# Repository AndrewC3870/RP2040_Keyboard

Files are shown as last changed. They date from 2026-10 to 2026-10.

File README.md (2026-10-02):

# RP2040_Keyboard
**Custom RP2040 mini keyboard for small portable projects!**
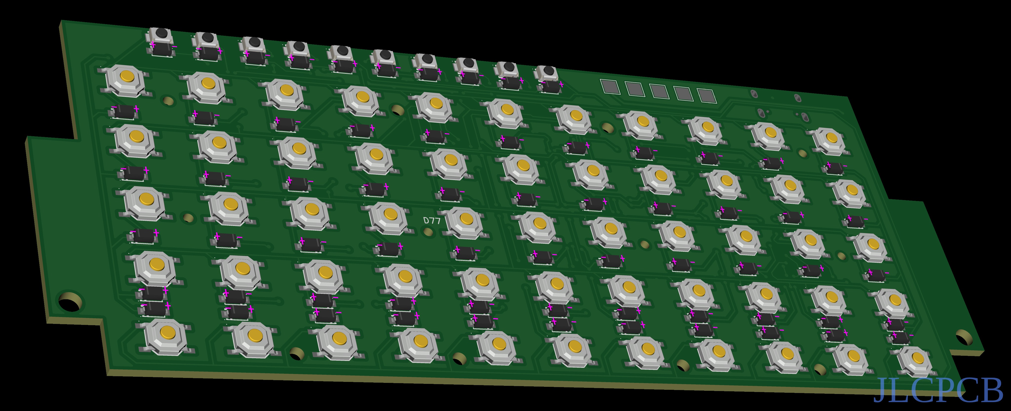
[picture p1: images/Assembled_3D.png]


## Features
* **Microcontroller:** RP2040
* **Layout:** 5x13 Ortholinear
* **Special Features:** Integrated Left D-pad and Right Action buttons directly in the QMK matrix.
* **Firmware:** QMK
---
## Keymap Layout
The default keymap includes a standard typing base layer, an Fn layer with navigation and F-keys, and dedicated hardware gamepad keys mapped to the outer columns (this was made using simple buttons footprint for custom soldering, also can be replaced with functional buttons).

* **Gamepad Left:** `Up`, `Down`, `Left`, `Right`
* **Gamepad Right:** `Y`, `A`, `X`, `B`
* **Bumpers:** `Page Up` (L1), `Page Down` (R1)

Also the test pads I added can be used to solder analog devices such as joystick or analog trigger.
If decided to add this features, then you'll need to add this changes into code and configure the keyboard.

---
## Flashing Instructions
**The code is for my specific build, but it can be easily change to satisfy your requirements**

To compile and flash this firmware, you will need the [QMK CLI](https://docs.qmk.fm/#/newbs_getting_started) installed.

1. Clone the `qmk_firmware` repository.
2. Clone or download this repository and place the `rp2040_keyboard` folder from `setup` into `qmk_firmware/keyboards/`.
3. Put your keyboard into bootloader mode.
4. Run the following command from the root of your `qmk_firmware` directory:

```bash
qmk flash -kb rp2040_keyboard -km default

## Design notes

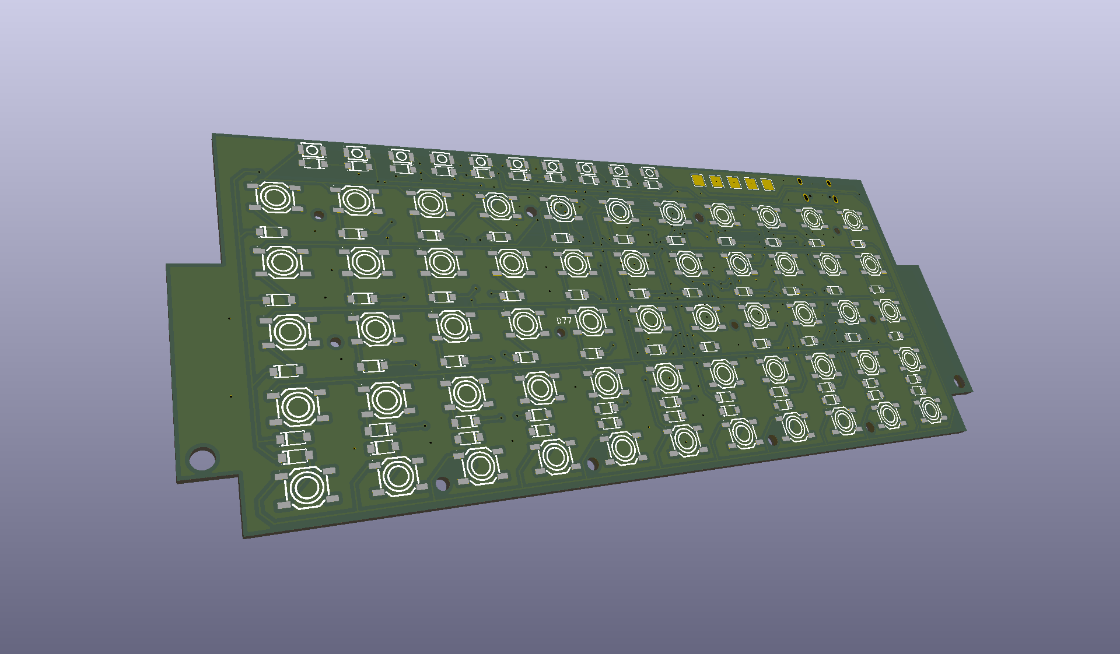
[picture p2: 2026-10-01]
images/keyboard_1.png

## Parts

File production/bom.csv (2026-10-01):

Designator | Footprint | Quantity | Value | LCSC Part #
100NF1, 100NF10, 100NF11, 100NF12, 100NF2, 100NF3, 100NF4, 100NF5, 100NF6, 100NF7, 100NF8, 100NF9 | C0603 | 12 | CC0603KRX7R8BB104 | C92490
10K1, 10K2, 10K3 | R0603 | 3 | RC0603FR-0710KL | C98220
15PF1, 15PF2 | C0603 | 2 | CC0603JRNPO9BN150 | C107037
1K1, 1K2 | R0603 | 2 | RC0603FR-071KL | C22548
1ΜF1, 1ΜF2, 1ΜF3, 1ΜF4 | C0805 | 4 | CC0805KKX5R6BB106 | C89832
27R1, 27R2 | R0603 | 2 | RC0603FR-0727RL | C137753
3V3, CLICK1, GND1, X2, Y1 | TestPoint_Pad_2.5x2.5mm | 5 | TestPoint
BOOT1, RESET1, SW1, SW10, SW11, SW12, SW13, SW14, SW15, SW16, SW17, SW18, SW19, SW2, SW20, SW21, SW22, SW23, SW24, SW25, SW26, SW27, SW28, SW29, SW3, SW30, SW31, SW32, SW33, SW34, SW35, SW36, SW37, SW38, SW39, SW4, SW40, SW41, SW42, SW43, SW44, SW45, SW46, SW47, SW48, SW49, SW5, SW50, SW51, SW52, SW53, SW54, SW55, SW6, SW7, SW8, SW9 | SW-SMD_4P-L5.2-W5.2-P3.70-LS6.4 | 57 | K2-1187SQ-A1SW-06 | C707331
D1 | SOT-23-6_L2.9-W1.6-P0.95-LS2.8-BL | 1 | USBLC6-2SC6 | C7519
D100, D111, D112, D113, D114, D115, D116, D117, D118, D119, D120, D121, D122, D123, D124, D125, D126, D127, D128, D129, D130, D131, D132, D133, D134, D135, D136, D137, D138, D139, D140, D66, D67, D68, D69, D70, D71, D72, D73, D74, D75, D76, D77, D78, D79, D80, D81, D82, D83, D84, D85, D86, D87, D88, D89, D90, D91, D92, D93, D94, D95, D96, D97, D98, D99 | SOD-123_L2.8-W1.8-LS3.7-RD | 65 | 1N4148W-C84367 | C84367
R1_5K1, R2_5K1 | R0603 | 2 | RC0603FR-075K1L | C105580
SW56, SW57, SW58, SW59, SW60, SW61, SW62, SW63, SW64, SW65 | KEY-SMD_B3U-1000PM | 10 | B3U-1000P | C231329
U1 | LQFN-56_L7.0-W7.0-P0.4-EP | 1 | RP2040 | C2040
U2 | SOT-25-5_L2.9-W1.6-P0.95-LS2.8-BL | 1 | AP2112K-3.3TRG1 | C51118
U3 | SOIC-8_L5.3-W5.3-P1.27-LS8.0-BL | 1 | W25Q16JVSSIQ | C82317
USBC1 | USB-C_SMD-TYPE-C-31-M-12_1 | 1 | TYPE-C-31-M-12 | C165948
X1 | CRYSTAL-SMD_4P-L3.2-W2.5-BL | 1 | X322512MOB4SI | C70565

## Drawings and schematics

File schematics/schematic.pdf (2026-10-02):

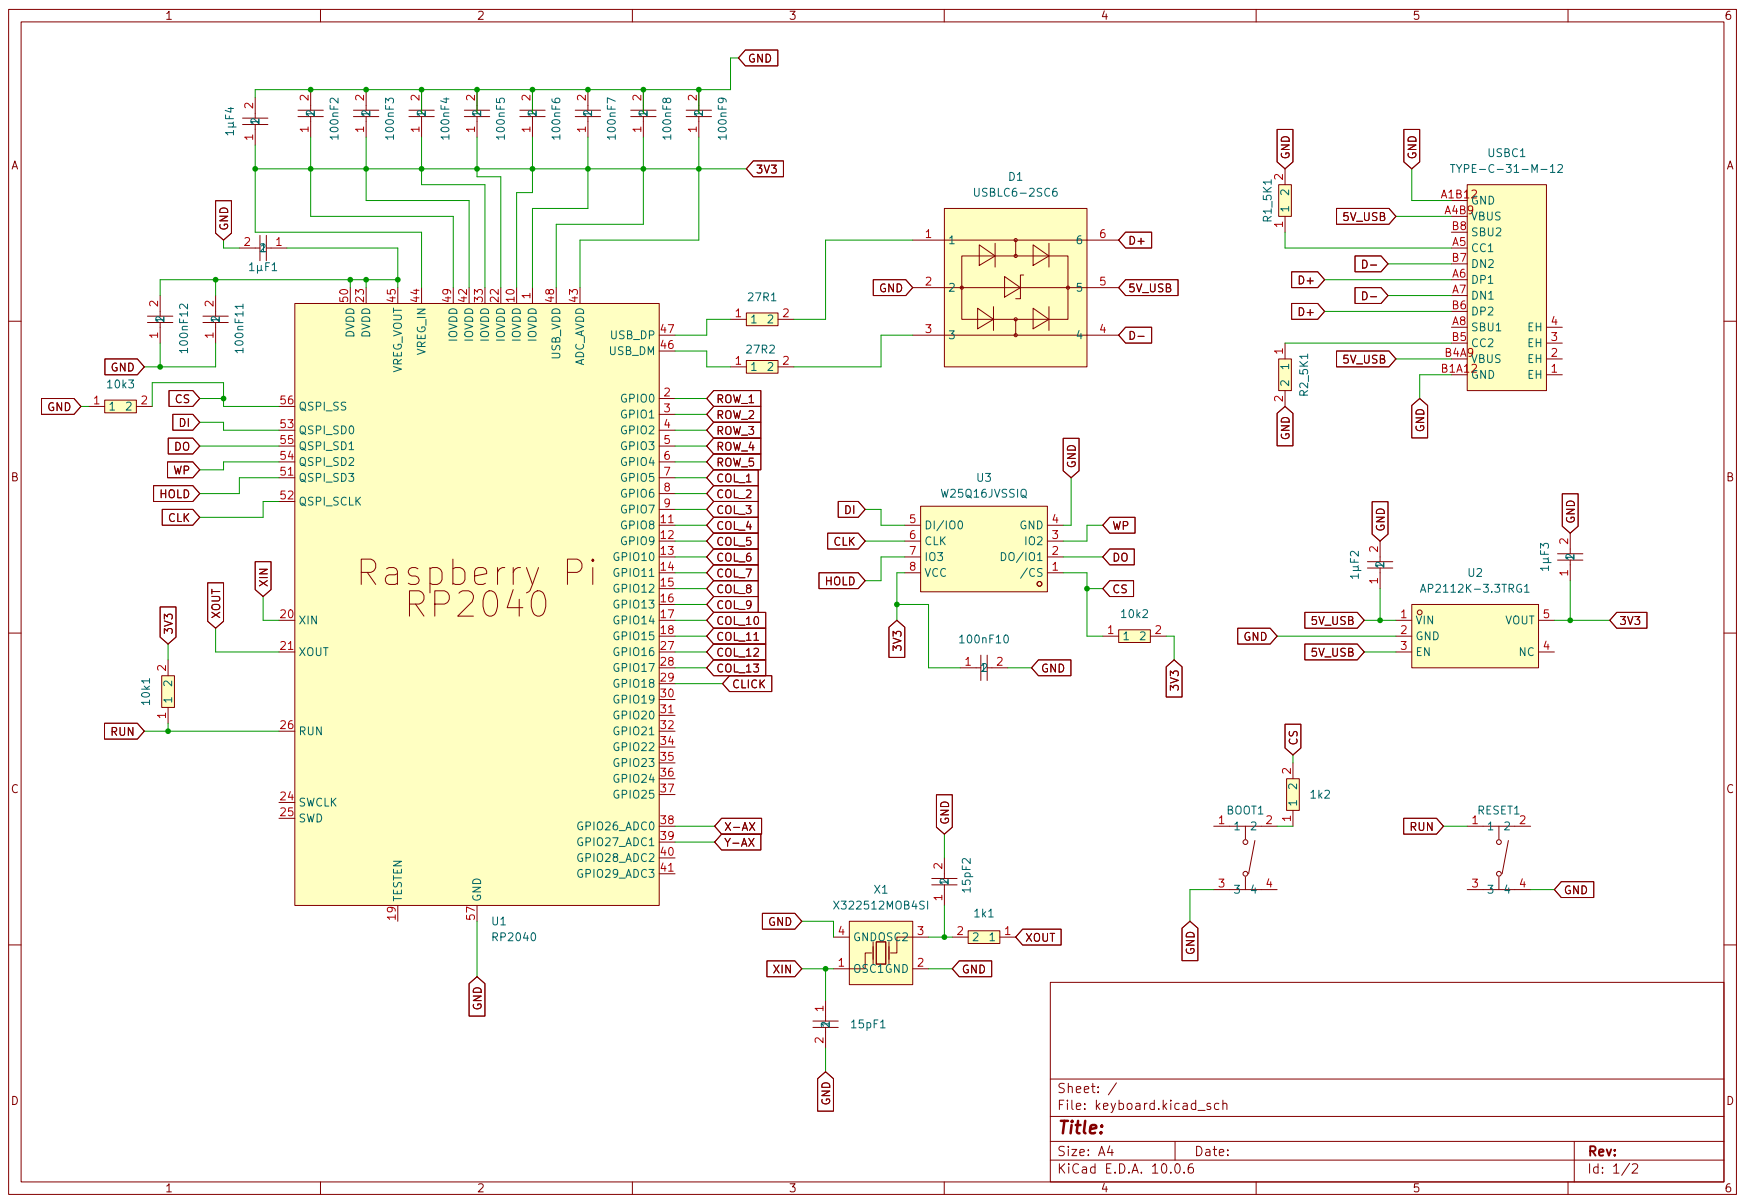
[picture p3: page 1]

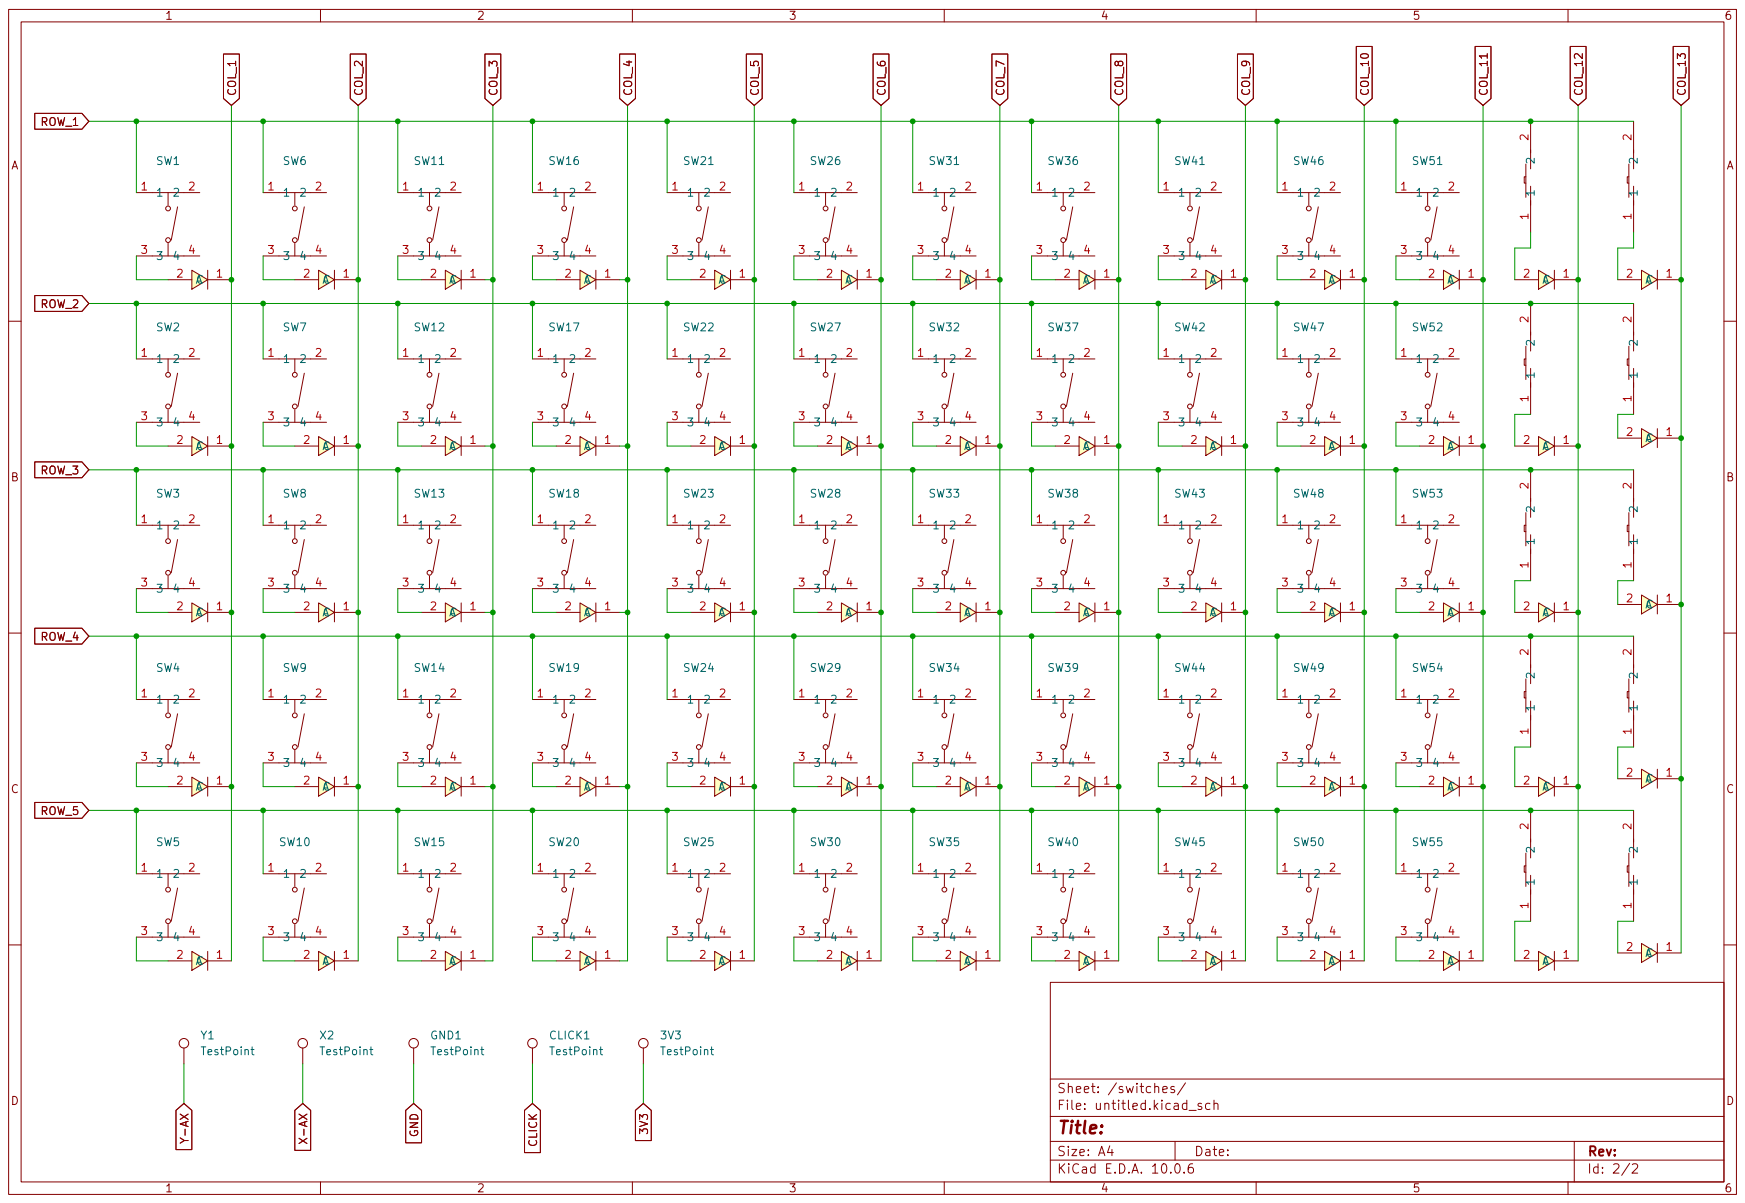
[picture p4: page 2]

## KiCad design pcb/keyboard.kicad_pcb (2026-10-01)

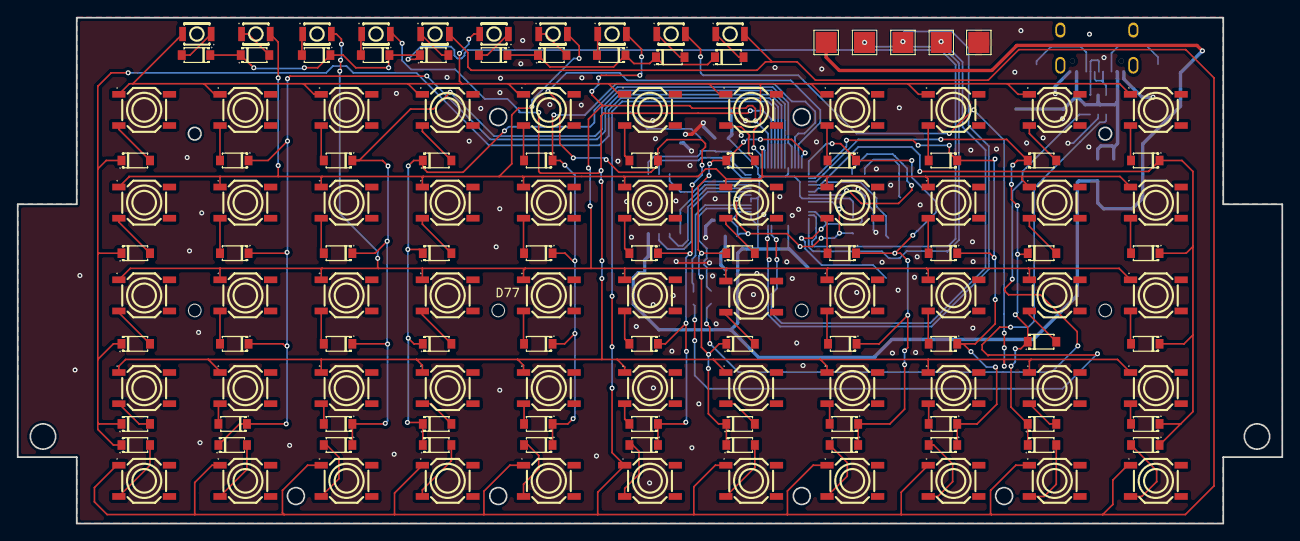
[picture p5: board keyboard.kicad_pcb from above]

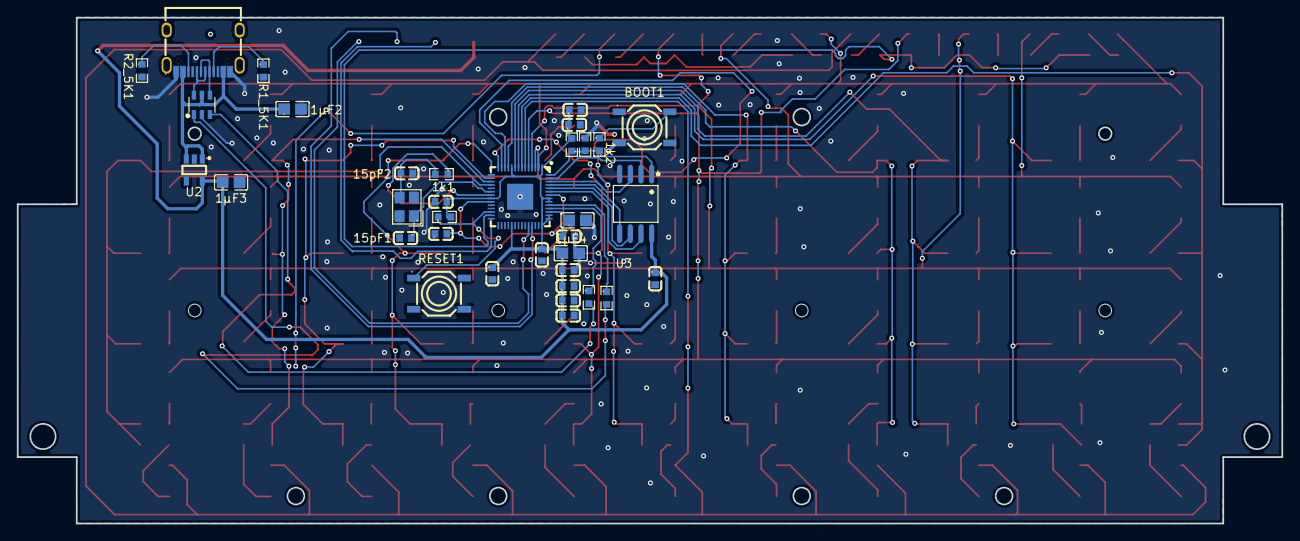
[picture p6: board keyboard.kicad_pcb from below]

Board: 2 copper layers, 150.0 x 60.0 mm, 170 parts (35 on the bottom side), 109 nets.

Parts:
1k1, 1k2: RC0603FR-071KL; R0603
1µF1, 1µF2, 1µF3, 1µF4: CC0805KKX5R6BB106; C0805
3V3: TestPoint; TestPoint_Pad_2.5x2.5mm
10k1, 10k2, 10k3: RC0603FR-0710KL; R0603
15pF1, 15pF2: CC0603JRNPO9BN150; C0603
27R1, 27R2: RC0603FR-0727RL; R0603
100nF1, 100nF2, 100nF3, 100nF4, 100nF5, 100nF6, 100nF7, 100nF8, 100nF9, 100nF10, 100nF11, 100nF12: CC0603KRX7R8BB104; C0603
BOOT1: K2-1187SQ-A1SW-06; SW-SMD_4P-L5.2-W5.2-P3.70-LS6.4
CLICK1: TestPoint; TestPoint_Pad_2.5x2.5mm
D1: USBLC6-2SC6; SOT-23-6_L2.9-W1.6-P0.95-LS2.8-BL
D66, D67, D68, D69, D70, D71, D72, D73, D74, D75, D76, D77, D78, D79, D80, D81, D82, D83, D84, D85, D86, D87, D88, D89, D90, D91, D92, D93, D94, D95, D96, D97, D98, D99, D100, D111, D112, D113, D114, D115, D116, D117, D118, D119, D120, D121, D122, D123, D124, D125, D126, D127, D128, D129, D130, D131, D132, D133, D134, D135, D136, D137, D138, D139, D140: 1N4148W-C84367; SOD-123_L2.8-W1.8-LS3.7-RD
GND1: TestPoint; TestPoint_Pad_2.5x2.5mm
R1_5K1, R2_5K1: RC0603FR-075K1L; R0603
RESET1: K2-1187SQ-A1SW-06; SW-SMD_4P-L5.2-W5.2-P3.70-LS6.4
SW1, SW2, SW3, SW4, SW5, SW6, SW7, SW8, SW9, SW10, SW11, SW12, SW13, SW14, SW15, SW16, SW17, SW18, SW19, SW20, SW21, SW22, SW23, SW24, SW25, SW26, SW27, SW28, SW29, SW30, SW31, SW32, SW33, SW34, SW35, SW36, SW37, SW38, SW39, SW40, SW41, SW42, SW43, SW44, SW45, SW46, SW47, SW48, SW49, SW50, SW51, SW52, SW53, SW54, SW55: K2-1187SQ-A1SW-06; SW-SMD_4P-L5.2-W5.2-P3.70-LS6.4
SW56, SW57, SW58, SW59, SW60, SW61, SW62, SW63, SW64, SW65: B3U-1000P; KEY-SMD_B3U-1000PM
U1: RP2040; LQFN-56_L7.0-W7.0-P0.4-EP
U2: AP2112K-3.3TRG1; SOT-25-5_L2.9-W1.6-P0.95-LS2.8-BL
U3: W25Q16JVSSIQ; SOIC-8_L5.3-W5.3-P1.27-LS8.0-BL
USBC1: TYPE-C-31-M-12; USB-C_SMD-TYPE-C-31-M-12_1
X1: X322512MOB4SI; CRYSTAL-SMD_4P-L3.2-W2.5-BL
X2: TestPoint; TestPoint_Pad_2.5x2.5mm
Y1: TestPoint; TestPoint_Pad_2.5x2.5mm

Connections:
3V3: 1µF3.1, 1µF4.1, 3V3.1 (1_1), 10k1.2, 10k2.2, 100nF1.1, 100nF2.1, 100nF3.1, 100nF4.1, 100nF5.1, 100nF6.1, 100nF7.1, 100nF8.1, 100nF9.1, 100nF10.1, U1.1 (IOVDD), U1.10 (IOVDD), U1.22 (IOVDD), U1.33 (IOVDD), U1.42 (IOVDD), U1.43 (ADC_AVDD), U1.44 (VREG_IN), U1.48 (USB_VDD), U1.49 (IOVDD), U2.5 (VOUT), U3.8 (VCC)
5V_USB: 1µF2.1, D1.5, U2.1 (VIN), U2.3 (EN), USBC1.A4B9 (VBUS), USBC1.B4A9 (VBUS)
CLICK: CLICK1.1 (1_1), U1.28 (GPIO17)
CLK: U1.52 (QSPI_SCLK), U3.6 (CLK)
COL_1: D66.1 (C), D67.1 (C), D68.1 (C), D69.1 (C), D70.1 (C), U1.7 (GPIO5)
COL_2: D71.1 (C), D72.1 (C), D73.1 (C), D74.1 (C), D75.1 (C), U1.8 (GPIO6)
COL_3: D76.1 (C), D77.1 (C), D78.1 (C), D79.1 (C), D80.1 (C), U1.9 (GPIO7)
COL_4: D81.1 (C), D82.1 (C), D83.1 (C), D84.1 (C), D85.1 (C), U1.11 (GPIO8)
COL_5: D86.1 (C), D87.1 (C), D88.1 (C), D89.1 (C), D90.1 (C), U1.12 (GPIO9)
COL_6: D91.1 (C), D92.1 (C), D93.1 (C), D94.1 (C), D95.1 (C), U1.13 (GPIO10)
COL_7: D96.1 (C), D97.1 (C), D98.1 (C), D99.1 (C), D100.1 (C), U1.14 (GPIO11)
COL_8: D132.1 (C), D133.1 (C), D135.1 (C), D137.1 (C), D139.1 (C), U1.15 (GPIO12)
COL_9: D131.1 (C), D134.1 (C), D136.1 (C), D138.1 (C), D140.1 (C), U1.16 (GPIO13)
COL_10: D111.1 (C), D112.1 (C), D113.1 (C), D114.1 (C), D115.1 (C), U1.17 (GPIO14)
COL_11: D116.1 (C), D117.1 (C), D118.1 (C), D119.1 (C), D120.1 (C), U1.18 (GPIO15)
COL_12: D126.1 (C), D127.1 (C), D128.1 (C), D129.1 (C), D130.1 (C), U1.27 (GPIO16)
COL_13: D121.1 (C), D122.1 (C), D123.1 (C), D124.1 (C), D125.1 (C)
CS: 1k2.2, 10k2.1, 10k3.2, U1.56 (QSPI_SS), U3.1 (/CS)
D+: D1.6, USBC1.A6 (DP1), USBC1.B6 (DP2)
D-: D1.4, USBC1.A7 (DN1), USBC1.B7 (DN2)
DI: U1.53 (QSPI_SD0), U3.5 (DI/IO0)
DO: U1.55 (QSPI_SD1), U3.2 (DO/IO1)
GND: 1µF1.2, 1µF2.2, 1µF3.2, 1µF4.2, 10k3.1, 15pF1.2, 15pF2.2, 100nF1.2, 100nF2.2, 100nF3.2, 100nF4.2, 100nF5.2, 100nF6.2, 100nF7.2, 100nF8.2, 100nF9.2, 100nF10.2, 100nF11.1, 100nF12.1, BOOT1.3, D1.2, GND1.1 (1_1), R1_5K1.2, R2_5K1.2, RESET1.4, U1.57 (GND), U2.2 (GND), U3.4 (GND), USBC1.A1B12 (GND), USBC1.B1A12 (GND), X1.2 (GND), X1.4 (GND)
HOLD: U1.51 (QSPI_SD3), U3.7 (IO3)
unnamed: 1k2.1, BOOT1.2
unnamed: 27R1.2, D1.1
unnamed: 27R2.2, D1.3
unnamed: D66.2 (A), SW1.3
unnamed: D67.2 (A), SW2.3
unnamed: D68.2 (A), SW3.3
unnamed: D69.2 (A), SW4.3
unnamed: D70.2 (A), SW5.3
unnamed: D71.2 (A), SW6.3
unnamed: D72.2 (A), SW7.3
unnamed: D73.2 (A), SW8.3
unnamed: D74.2 (A), SW9.3
unnamed: D75.2 (A), SW10.3
unnamed: D76.2 (A), SW11.3
unnamed: D77.2 (A), SW12.3
unnamed: D78.2 (A), SW13.3
unnamed: D79.2 (A), SW14.3
unnamed: D80.2 (A), SW15.3
unnamed: D81.2 (A), SW16.3
unnamed: D82.2 (A), SW17.3
unnamed: D83.2 (A), SW18.3
unnamed: D84.2 (A), SW19.3
unnamed: D85.2 (A), SW20.3
unnamed: D86.2 (A), SW21.3
unnamed: D87.2 (A), SW22.3
unnamed: D88.2 (A), SW23.3
unnamed: D89.2 (A), SW24.3
unnamed: D90.2 (A), SW25.3
unnamed: D91.2 (A), SW26.3
unnamed: D92.2 (A), SW27.3
unnamed: D93.2 (A), SW28.3
unnamed: D94.2 (A), SW29.3
unnamed: D95.2 (A), SW30.3
unnamed: D96.2 (A), SW31.3
unnamed: D97.2 (A), SW32.3
unnamed: D98.2 (A), SW33.3
unnamed: D99.2 (A), SW34.3
unnamed: D100.2 (A), SW35.3
unnamed: D111.2 (A), SW46.3
unnamed: D112.2 (A), SW47.3
unnamed: D113.2 (A), SW48.3
unnamed: D114.2 (A), SW49.3
unnamed: D115.2 (A), SW50.3
unnamed: D116.2 (A), SW51.3
unnamed: D117.2 (A), SW52.3
unnamed: D118.2 (A), SW53.3
unnamed: D119.2 (A), SW54.3
unnamed: D120.2 (A), SW55.3
unnamed: D121.2 (A), SW61.1
unnamed: D122.2 (A), SW62.1
unnamed: D123.2 (A), SW63.1
unnamed: D124.2 (A), SW64.1
unnamed: D125.2 (A), SW65.1
unnamed: D126.2 (A), SW56.1
unnamed: D127.2 (A), SW57.1
unnamed: D128.2 (A), SW58.1
unnamed: D129.2 (A), SW59.1
unnamed: D130.2 (A), SW60.1
unnamed: D131.2 (A), SW41.3
unnamed: D132.2 (A), SW36.3
unnamed: D133.2 (A), SW37.3
unnamed: D134.2 (A), SW42.3
unnamed: D135.2 (A), SW38.3
unnamed: D136.2 (A), SW43.3
unnamed: D137.2 (A), SW39.3
unnamed: D138.2 (A), SW44.3
unnamed: D139.2 (A), SW40.3
unnamed: D140.2 (A), SW45.3
unnamed: 27R2.1, U1.46 (USB_DM)
unnamed: 27R1.1, U1.47 (USB_DP)
unnamed: 1µF1.1, 100nF11.2, 100nF12.2, U1.23 (DVDD), U1.45 (VREG_VOUT), U1.50 (DVDD)
unnamed: R1_5K1.1, USBC1.A5 (CC1)
unnamed: R2_5K1.1, USBC1.B5 (CC2)
unnamed: 1k1.2, 15pF2.1, X1.3 (OSC2)
ROW_1: SW1.1, SW6.1, SW11.1, SW16.1, SW21.1, SW26.1, SW31.1, SW36.1, SW41.1, SW46.1, SW51.1, SW56.2, SW61.2, U1.2 (GPIO0)
ROW_2: SW2.1, SW7.1, SW12.1, SW17.1, SW22.1, SW27.1, SW32.1, SW37.1, SW42.1, SW47.1, SW52.1, SW57.2, SW62.2, U1.3 (GPIO1)
ROW_3: SW3.1, SW8.1, SW13.1, SW18.1, SW23.1, SW28.1, SW33.1, SW38.1, SW43.1, SW48.1, SW53.1, SW58.2, SW63.2, U1.4 (GPIO2)
ROW_4: SW4.1, SW9.1, SW14.1, SW19.1, SW24.1, SW29.1, SW34.1, SW39.1, SW44.1, SW49.1, SW54.1, SW59.2, SW64.2, U1.5 (GPIO3)
ROW_5: SW5.1, SW10.1, SW15.1, SW20.1, SW25.1, SW30.1, SW35.1, SW40.1, SW45.1, SW50.1, SW55.1, SW60.2, SW65.2, U1.6 (GPIO4)
RUN: 10k1.1, RESET1.1, U1.26 (RUN)
WP: U1.54 (QSPI_SD2), U3.3 (IO2)
X-AX: U1.38 (GPIO26_ADC0), X2.1 (1_1)
XIN: 15pF1.1, U1.20 (XIN), X1.1 (OSC1)
XOUT: 1k1.1, U1.21 (XOUT)
Y-AX: U1.39 (GPIO27_ADC1), Y1.1 (1_1)

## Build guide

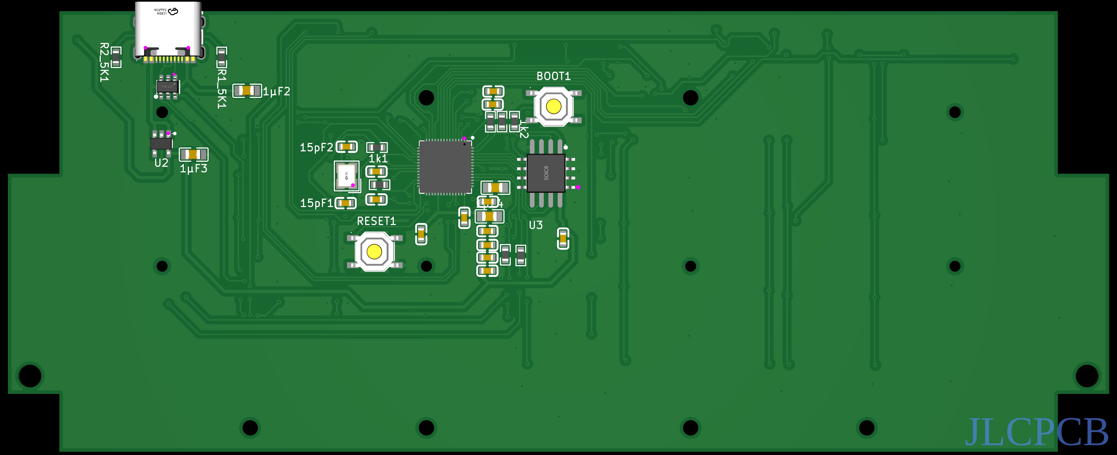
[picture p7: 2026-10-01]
images/Assembled_bottom_2D.png

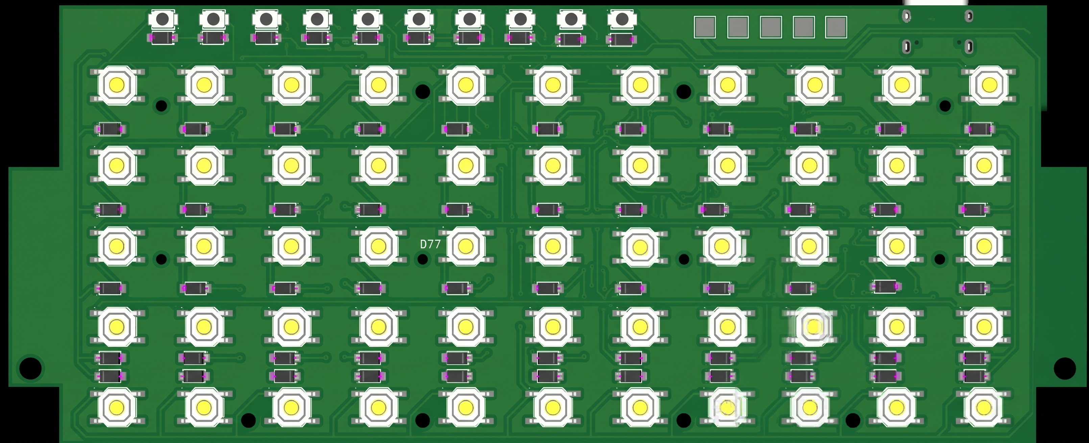
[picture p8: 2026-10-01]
images/Assembled_top_2D.jpeg

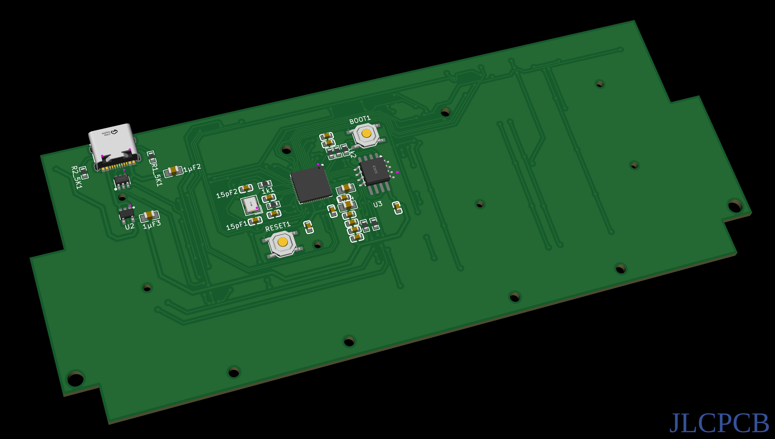
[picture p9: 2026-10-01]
images/Assembled_Bottom_3D.png

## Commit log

2026-10-01 upload files and images
    [bom.csv, designators.csv, keyboard.kicad_pcb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]
2026-10-02 added configuration code and fixed the schematic
    [Orar5CMasterCTI.xlsx, keyboard.kicad_sch]
2026-10-02 Update README
    Added information about using test pads for analog devices.
